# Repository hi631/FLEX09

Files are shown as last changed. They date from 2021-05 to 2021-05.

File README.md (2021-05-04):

<p><b><font size="+1"><span class="VIiyi" jsaction="mouseup:BR6jm" jsname="jqKxS" lang="en" style="-webkit-tap-highlight-color: transparent; display: inline; color: rgb(0, 0, 0); font-family: Roboto, RobotoDraft, Helvetica, Arial, sans-serif; font-size: 24px; font-style: normal; font-variant-ligatures: normal; font-variant-caps: normal; font-weight: 400; letter-spacing: normal; orphans: 2; text-align: start; text-indent: 0px; text-transform: none; white-space: pre-wrap; widows: 2; word-spacing: 0px; -webkit-text-stroke-width: 0px; background-color: rgb(245, 245, 245); text-decoration-thickness: initial; text-decoration-style: initial; text-decoration-color: initial;"><span jsaction="agoMJf:PFBcW;usxOmf:aWLT7;jhKsnd:P7O7bd,F8DmGf;Q4AGo:Gm7gYd,qAKMYb;uFUCPb:pvnm0e,pfE8Hb,PFBcW;f56efd:dJXsye;EnoYf:KNzws,ZJsZZ,JgVSJc;zdMJQc:cCQNKb,ZJsZZ,zchEXc;Ytrrj:JJDvdc;tNR8yc:GeFvjb;oFN6Ye:hij5Wb" jscontroller="Zl5N8" jsmodel="SsMkhd" jsname="txFAF" class="JLqJ4b ChMk0b" data-language-for-alternatives="en" data-language-to-translate-into="ja" data-phrase-index="0" jsdata="uqLsIf;_;$7" style="-webkit-tap-highlight-color: transparent; cursor: pointer;"><span jsaction="click:qtZ4nf,GFf3ac,tMZCfe; contextmenu:Nqw7Te,QP7LD; mouseout:Nqw7Te; mouseover:qtZ4nf,c2aHje" jsname="W297wb" style="-webkit-tap-highlight-color: transparent;">Make 6809 with FPGA and run FLEX</span></span></span><span style="color: rgb(0, 0, 0); font-family: Roboto, RobotoDraft, Helvetica, Arial, sans-serif; font-size: 24px; font-style: normal; font-variant-ligatures: normal; font-variant-caps: normal; font-weight: 400; letter-spacing: normal; orphans: 2; text-align: start; text-indent: 0px; text-transform: none; white-space: pre-wrap; widows: 2; word-spacing: 0px; -webkit-text-stroke-width: 0px; background-color: rgb(245, 245, 245); text-decoration-thickness: initial; text-decoration-style: initial; text-decoration-color: initial; display: inline !important; float: none;"> </span></font></b></p>
<p><font size="+1">#Simulator (SIM6809)</font><br>
<a>original material</a>[<a href="https://github.com/gordonjcp/sim6809">SIM6809</a>]<br>
SIM6809 is compiled with MINGW32.<br>
Start MINGW32 and move to the source directory with &quot;cd / C / ...... / sim6809&quot;,<br>
Compile with one make, start with &quot;./sim6809&quot; and the prompt should appear.<br>
<br>
<font size="+1"># FLEX</font><br>
Portable by adding serial and SD drivers to DRIVER (file is CONSOLE).<br>
The OS is localized to  $ C000-  $ FFFF, and it may not be possible to
move. The user area is 48KB.<br>
Add necessary processing (input / output) and check the operation of the assembled HEX with the simulator.<br>
<br>
There is a sample of access to the SD card at [<a href="https://github.com/nealcrook/multicomp6809">MULTICOMP6809</a>].<br>
However, FLEX has 256 bytes / sector, while SD card has 512 bytes / sector.<br>
The sample was a method that did not use half of the 512 bytes, but it was divided R / W using a buffer.<br>
<br>
Batch job &quot;_flex_SIM.bat&quot; creates HEX for the simulator.<br>
* Drive is R / W for files on Windows.<br>
Batch job &quot;_flex_FPGA.bat&quot; creates HEX for FPGA.<br>
* The drive is R / W by dividing the SD card.<br>
<br>
Furthermore, since it does not work under windows already, use an extender called msdos.exe.<br>
[<a href="http://takeda-toshiya.my.coocan.jp/msdos/">MS-DOS Player for Win32-x64</a>] <br>
<br>
<font size="+1"># FPGA6809 hard</font><br>
It would be easier to understand the configuration by looking at [<a href="http://searle.x10host.com/Multicomp/index.html">Grant's MULTICOMP</a>].<br>
* Almost as it is. However, VHDL is converted to verilog.<br>
6809 is operating at 30MHz.<br>
The SD card gives the driver 20MHz, so it probably works at 10MHz.<br>
<br>
Green is EP2C5 mounted board, black and big is FPGA<br>
The board on it is a board with RAM and SD made by CNC<br>
The lower right is the serial board (commercially available FTD1232)<br>
The upper right is the VGA output and PS2 input board (not connected in this software)<br>
<br>
<font size="+1">#FPGA6809 software</font><br>
The software can be compiled with quartus II.<br>
EP2C5 is an old generation Cyclone II, so be careful as it can only be compiled before 13.0sp1.<br>
1. If you want to run BASIC, assemble basic.asm.<br>
2. If you want to run monitor, assemble monitor.asm.<br>
* Both generate basic.hex, so there is no need to change the verilog side.<br>
<br>
<font size="+1">#Monitor program</font><br>
Used for starting FLEX and debugging when FLEX does not start.<br>
Starting FLEX is<br>
1. After starting the monitor, press'B'+'Ret' to start. (Pre-setting required)<br>
2. It is also possible to start from BASIC, and'%' is displayed by'Ctrl' +'L', so copy and paste the FLEX HEX file on the screen.<br>
Automatically start after the message &quot;% %%% ...&quot; is displayed<br>
* It is assumed that basic.asm (modified version) under the moni09 directory is used. It will be started from \ $ C400.<br>
The monitor is localized in two places,  $ E000 and \  A000, and starts
as  $ A000 at the time of reset.<br>
After copying itself to the RAM of \  A000, invalidate the ROM and free
up the FLEX load area.<br>
<br>
<font size="+1">#Drive layout on SD card</font><br>
0000-059F drive 0<br>
05A0 --05CF boot loader<br>
0800-0D9F drive 1<br>
1000-159F drive 2<br>
1800-1D9F drive 3<br>
* Described as 512B / S<br>
* 4 units can be selected, but the 4th unit cannot be used. (I feel like it's 3 in FLEX)<br>
For Card Day, use the command as shown below to combine the disks and write to SD with win32diskimager.<br>
Copy /b FLEX9SYS.DSK + DUMY_4CKFF.bin + BLANK.DSK + DUMY_4CKFF.bin + BLANK.DSK + DUMY_4CKFF.bin SD4M.img<br>
* Obtain FLEX9SYS.DSK from [<a href="http://www.evenson-consulting.com/swtpc/">SWTPC</a>]. I don't think there were any particular restrictions on use.<br>
<br>
<br>
<font size="+1">#Boot loader settings</font><br>
1. The monitor starts by resetting.<br>
2. Issue the'L'command. Check the'%' display.Copy and paste <br>
3.flex9.hexe to the terminal and load it into memory. (Written to $ C000-
$ FFFF)<br>
4. Issue a write command with'W 5001 C000 3F'.<br>
* 5001 is equivalent to  $ 800 sector (512B / S conversion) on the card.<br>
5. Confirm the operation with the'B'command.<br>
<br>
<a href="https://qiita.com/hi631/items/5b386fb230afcc87c66d">Here is</a> a little more detailed explanation (but in Japanese) <br>
<br>
</p>

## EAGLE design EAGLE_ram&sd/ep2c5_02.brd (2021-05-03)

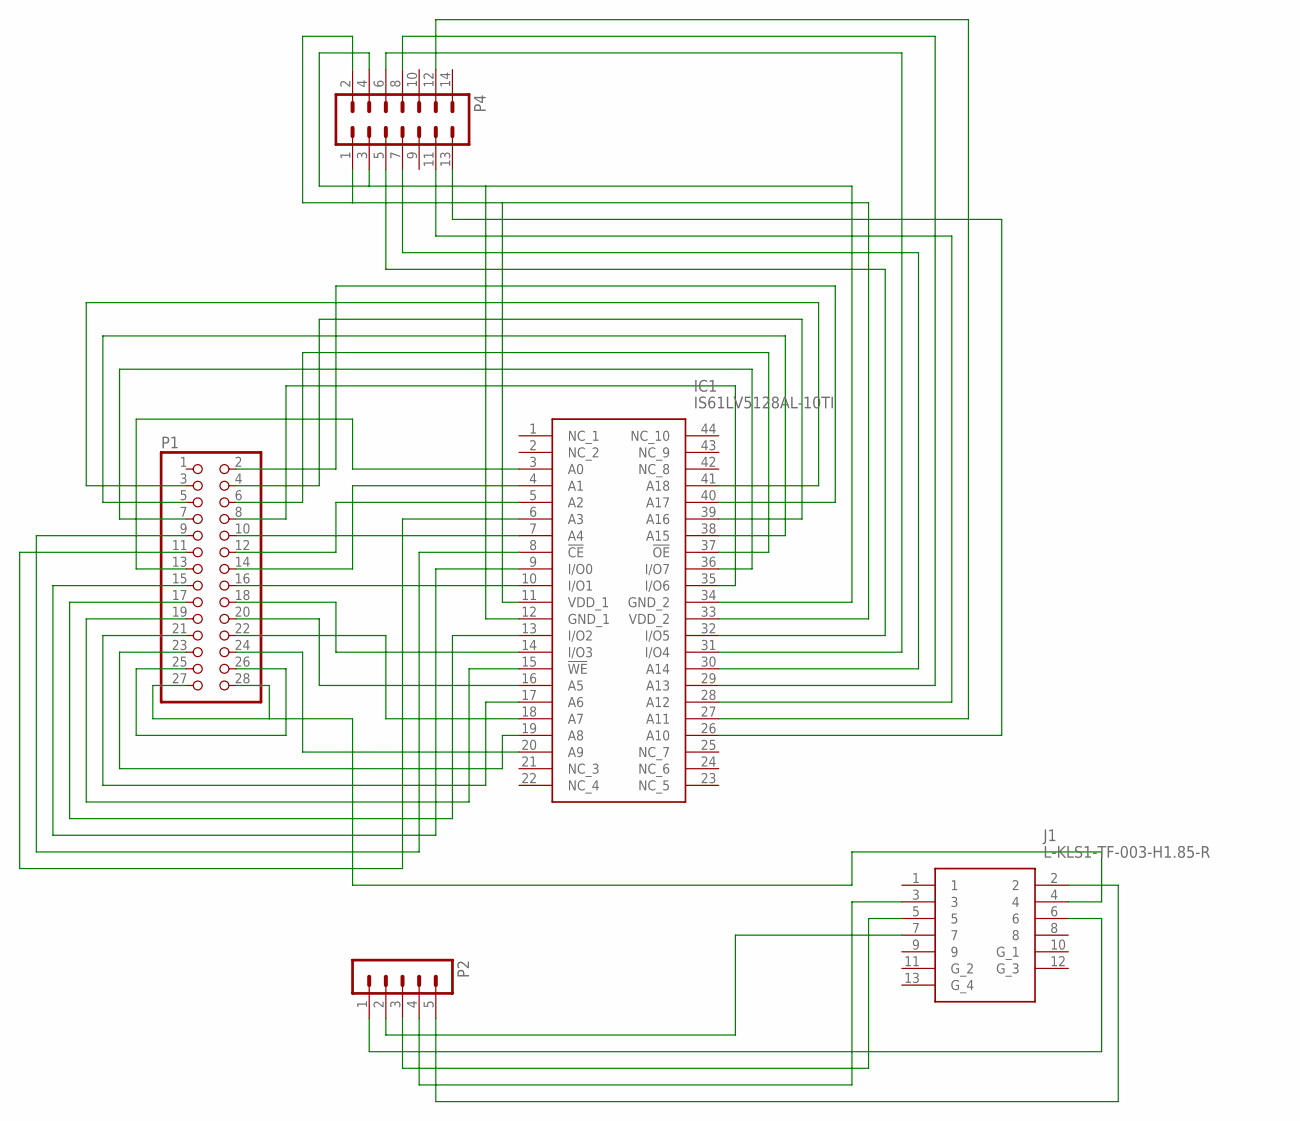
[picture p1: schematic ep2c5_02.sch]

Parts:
IC1: IS61LV5128AL-10TI; SOP80P1176X120-44N
J1: L-KLS1-TF-003-H1.85-R
P1: PINHD-2X14; 2X14
P2: MA05-1
P4: MA07-2

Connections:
unnamed: J1.4, P1.27, P1.28
unnamed: IC1.20 (A9), P1.24
unnamed: P1.25, P1.26
unnamed: IC1.19 (A8), P1.23
unnamed: IC1.18 (A7), P1.22
unnamed: IC1.17 (A6), P1.21
unnamed: IC1.16 (A5), P1.20
unnamed: IC1.15 (!WE), P1.19
unnamed: IC1.14 (I/O3), P1.18
unnamed: IC1.13 (I/O2), P1.17
unnamed: IC1.10 (I/O1), P1.16
unnamed: IC1.9 (I/O0), P1.15
unnamed: IC1.12 (GND_1), IC1.34 (GND_2), P4.3, P4.4
unnamed: IC1.8 (!CE), P1.9
unnamed: IC1.7 (A4), P1.10
unnamed: IC1.6 (A3), P1.11
unnamed: IC1.4 (A1), P1.14
unnamed: IC1.3 (A0), P1.13
unnamed: IC1.35 (I/O6), P1.8
unnamed: IC1.36 (I/O7), P1.7
unnamed: IC1.11 (VDD_1), IC1.33 (VDD_2), P4.1, P4.2
unnamed: IC1.37 (!OE), P1.6
unnamed: IC1.38 (A15), P1.5
unnamed: IC1.39 (A16), P1.4
unnamed: IC1.41 (A18), P1.3
unnamed: IC1.40 (A17), P1.2
unnamed: IC1.32 (I/O5), P4.5
unnamed: IC1.31 (I/O4), P4.6
unnamed: IC1.30 (A14), P4.7
unnamed: IC1.29 (A13), P4.8
unnamed: IC1.28 (A12), P4.11
unnamed: IC1.27 (A11), P4.12
unnamed: IC1.26 (A10), P4.13
unnamed: J1.7, P2.2
unnamed: J1.6, P2.1
unnamed: J1.5, P2.3
unnamed: J1.3, P2.4
unnamed: J1.2, P2.5
unnamed: IC1.5 (A2), P1.12

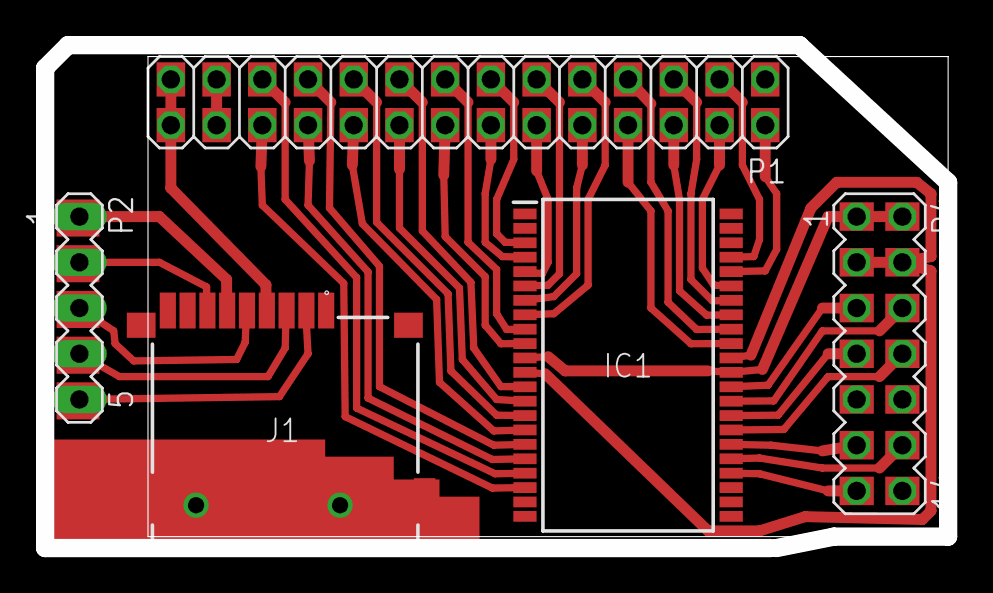
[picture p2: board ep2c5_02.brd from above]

Board: 2 copper layers, 44.5 x 26.7 mm, 5 parts (0 on the bottom side), 39 nets.

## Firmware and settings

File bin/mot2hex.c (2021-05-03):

/*
 * Motorola S1 format to Intel hex format
 * Usage
 * mot2hex <file_name>
 */

#include <stdio.h>
#include <string.h>


int gethex( FILE *fp_in )
{
    int hex;

    hex = fgetc( fp_in );
    if( (hex >= '0') && (hex <= '9' ))
	hex -= '0';
    else if( (hex >= 'A') && (hex <= 'F'))
	hex = hex - 'A' + 10;
    else
	hex = -1;
    return hex;
}

int get2hex( FILE *fp_in )
{
    int hexhi, hexlo, byte;

    hexhi = gethex( fp_in );
    if( hexhi != -1 )
    {
	hexlo = gethex( fp_in );
	if( hexlo != -1 )
	{
	    byte = hexhi * 16 + hexlo;
	    return byte;
	}
    }
    return -1;
}

int get4hex( FILE *fp_in )
{
    int bytehi, bytelo, addr;

    bytehi = get2hex( fp_in );
    if( bytehi != -1 )
    {
	bytelo = get2hex( fp_in );
	if( bytelo != -1 )
	{
	    addr = (bytehi * 256) + bytelo;
	    return addr;
	}
    }
    return -1;
}    


int main( int argc, char *argv[] )
{
	FILE *fp_in, *fp_out;
	char fname_in[32];
	char fname_out[32];
	int byte, addr, start, pstart,i;
        int motorola_check, intel_check;
	int motorola_count, intel_count;

	if( argc != 2 )
	{
	    printf( "\n usage: mot2hex <file_name> \n" );
	    return (0);
	}
 	sprintf( fname_in, "%s.s19", argv[1] );
	fp_in = fopen( fname_in, "r" );
	if( !fp_in )
	{
 	    sprintf( fname_in, "%s.s1", argv[1] );
            fp_in = fopen( fname_in, "r" );
	    if( !fp_in )
	    {
	        printf( "Can't open %s", fname_in );
	        return (0);
            }
	}
 	sprintf( fname_out, "%s.hex", argv[1] );
	fp_out = fopen( fname_out, "w" );
	if( !fp_out )
	{
	    printf( "Can't open %s", fname_out );
	    return (0);
	}
	byte = 0;
	addr = 0;
        start = -1; pstart = -1;

	while( byte != -1 )
	{
	    /*
	     * Motorola 8 bit record starts with "S1"
	     */
	    do {
		byte = fgetc( fp_in);
	    } while( (byte != 'S') && (byte != -1) );

	    byte = fgetc( fp_in );
	    if( byte == '1' )
	    {
		/*
		 * get byte count from Motorola record
		 */
		motorola_count = get2hex( fp_in );
	    motorola_check = motorola_count;
		/*
		 * Intel byte count is for data field only
		 * round up to even byte boundary
		 */
		intel_count = motorola_count - 3;
		intel_check = intel_count;
		/*
		 * Get two byte motorola address field
		 */
		addr = get4hex( fp_in );
                if(pstart==-1) pstart = addr;
	    motorola_check += (addr & 0xff); 
		motorola_check += (addr & 0xff00) >> 8;
		/*
		 * output intel start of record
		 * ":" <data count> <address> <record type>
		 */
		intel_check += (addr & 0xff);
		intel_check += (addr & 0xff00) >> 8;
	        fprintf( fp_out, ":%02X%04X00", intel_count, addr );
		/*
		 * Input Motorola data field
		 */
	    for( i=0; i<intel_count; i++ )
	        {
		    byte = get2hex( fp_in );
	            motorola_check += byte;
		    /*
		     * Output Intel data field
		     */
		    intel_check += byte;
		    fprintf( fp_out, "%02X", byte );
		    /*
		     * Get the start of record from the reset vector
		     */
	            if( addr == 0xfffe )
		        start = byte * 256;
	            if( addr == 0xffff )
		        start += byte;
		    addr ++;
		}
		/*
		 * Display Motorola cehcksum for current record
		 * should be 0xff
		 */	
	        byte = get2hex( fp_in) & 0xff;
	        motorola_check += byte;
		    motorola_check &= 0xff;
	        //printf( " Motorola checksum = %02X   ", motorola_check );
		/*
		 * Display Intel checksum
		 */
		intel_check &= 0xff;
		intel_check = 0x100 - intel_check;
		intel_check &= 0xff;
	        //printf( "Intel checksum = %02X \n", intel_check );
		/*
		 * Output Intel checksum
		 */
	        fprintf( fp_out, "%02X\n", intel_check);
	        if( addr > 0xffff )
		   byte = -1;
	     }
	}
	/*
	 * output Intel trasfer address
	 */
	//if( start != -1 )
	{
	    fprintf( fp_out, ":00%04X01", pstart );
	}
	/*
	 * Close input and output files and exit
	 */
	fclose( fp_in );
	fclose( fp_out );
}

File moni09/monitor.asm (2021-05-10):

ROMBASE   EQU  $9000          MONITOR $9000=RUN.RAM  $A000=RUN.ROM(->RAM)

UART      EQU  $FFD0
RECEV     EQU  UART+1
TRANS     EQU  UART+1
USTAT     EQU  UART
UCTRL     EQU  UART
SYSCTRL   EQU  $FFFF
RTS_LOW   EQU  $15

BS        EQU  8              BACKSPACE
CR        EQU  $D             ENTER KEY
ESC       EQU  $1B            ESCAPE CODE
SPACE     EQU  $20            SPACE (BLANK)

          ORG  $200          MONITOR WORK
MONCMD    RMB  1
MONAD     RMB  2
MONAD2    RMB  2
MONAD3    RMB  2
MONWK0    RMB  1
MONWK1    RMB  1
HLOADAD   RMB  2
HLOADDL   RMB  1
HLOADWK   RMB  1
HNINPWK   RMB  1

          ORG  ROMBASE
          JMP  BSTART           BASIC ENTRY
RSTART    LDS  #$1EE		RESET START
          LDX  #ROMBASE
          LDA  #$5A
          STA  -1,X
          LDB  #$A5
          STB  -2,X
          CMPA -1,X		IS RAM ?
          BNE  MONI
RSTARTLP  LDA  0,X		COPY ROM -> RAM
          STA  0,X
          LEAX 1,X
          CMPX #ROMBASE+$2000
          BNE  RSTARTLP
BSTART    
          PSHS X,Y,B,A
          LDA  #$81
          STA  SYSCTRL		DISALE BASIC.ROM
          BSR  MONI
          LDA  #$00
          STA  SYSCTRL		ENABLE BASIC.ROM
          PULS A,B,Y,X
          CLRA
          RTS

DLYT      CLRA
DLYA      DECA
          BNE  DLYA
          RTS
INITACIA  LDA  #3             RESET ACIA
          STA  UCTRL
          BSR  DLYT
          LDA  #RTS_LOW       DIV16 CLOCK -> 7372800 / 4 / 16 = 115200
          STA  UCTRL
          BSR  DLYT
          RTS

MONI      BSR  INITACIA
          LDX  #INITMSG
          JSR  STROUT
          
MONI2     LDA  #$3E		>
          JSR  PUTCHR
          JSR  CONSINWE
          STA  MONCMD
          CMPA #$0D
          BEQ  MONI
          JSR  HNINP		MONAD <- INPUT.HEX
          
MONI3     LDA  MONCMD
          CMPA #$44		D = DUMP(D AAAA)
          BNE  MONI4
          JSR  DUMP
          LBRA  MONIE
MONI4     CMPA #$4C		L = LOAD(LOAD HEX)
          BNE  MONI5
          JSR  HLOAD
          BRA  MONIE
MONI5     CMPA #$53		S = SYSTEM(S81 OR S00)
          BNE  MONI6
          LDA  MONAD+1
          STA  SYSCTRL		SET SYS_CTRL
          BRA  MONIE
MONI6     CMPA #$46		F = FILL(F AAAA BBBB DD)
          BNE  MONI7
          JSR  FILLDT
          BRA  MONIE
MONI7     CMPA #$47		G = GO.PRG(G AAAA)
          BNE  MONI8
          LDX  MONAD
          JSR  0,X
          BRA  MONIE
MONI8     CMPA #$52		R = READ(R SDAD MEMAD SDLEN)
          BNE  MONI9
          CLRA
          JSR  SDRWC		SDREAD(256B)
          BRA  MONIE
MONI9     CMPA #$57		W = WRITE(W SDAD MEMAD SDLEN)
          BNE  MONI10
          LDA  #1
          JSR  SDRWC
          BRA  MONIE
MONI10    CMPA #$55		U = UINT.SELECT(U N)
          BNE  MONI11
          LDA  MONAD+1
          LDX  #SDFCBTMP
          STA  3,X		DRIVE.NO
          JSR  SDSELDRV
          LDX  #SDDRV
          LDA  0,X
          JSR  H2OUT
          LDD  1,X
          JSR  H4OUT
          BRA  MONIE
MONI11    CMPA #$42		B = BOOT
          BNE  MONI99
          LDD  #$5001		SD.ADDR = 80T/1S
          STD  MONAD2
          LDD  #$C000		MEM.ADDR = $C000
          STD  MONAD3
          CLR  MONCMD		CMD(READ)
          LDB  #$3F		LOOP.COUNT
          JSR  SDRWCLP
          LDX  #$CD00
          JSR  0,X		JMP FLEX
          BRA  MONIE

MONI99    CMPA #$51		Q
          BNE  MONIE
          RTS
MONIE     JSR  CROUT
          LBRA  MONI2

SDRWC     STA  MONCMD
          LDD  MONAD
          STD  MONAD2          SD.AD
          JSR  HNINP
          PSHS A
          LDD  MONAD
          STD  MONAD3          MEM.AD
          PULS A
          CMPA #$8D
          BEQ  SDRWEX           R/W ONE
          JSR  HNINP
          LDD  MONAD
          LDB  MONAD+1		LOOP COUNT
*
SDRWCLP   PSHS B
          BSR  SDRWEX
          LDD  MONAD2
          ADDD #1
          STD  MONAD2
          LDD  MONAD3
          ADDD #256
          STD  MONAD3
          PULS B
          DECB
          BNE  SDRWCLP
          RTS
          
SDRWEX    LDD  MONAD2		TRACK.SECTER
          LDX  MONAD3		R/W.BUF.ADR
          TST  MONCMD           0=READ / 1=WRITE
          BNE  SDRWEX2
          JSR  SDREAD
          RTS
SDRWEX2   JSR  SDWRITE		SDWRITE(256B)
          RTS

FILLDT    LDD  MONAD
          STD  MONAD2		START
          JSR  HNINP
          LDD  MONAD
          STD  MONAD3		END
          JSR  HNINP
          LDA  MONAD+1		FILL.DT
          LDX  MONAD2
FILDT2    STA  0,X
          CMPX MONAD3
          BNE  FILDT3
          RTS
FILDT3    LEAX 1,X
          BRA  FILDT2


DUMP      TST  HNINPWK
          BEQ  DUMPEX
          LDX  MONAD
          STX  MONAD2
DUMPEX    LDB  #8
          STB  MONWK0
DUMPLP2   LDX  MONAD2
          LDD  MONAD2
          JSR  H4OUT
          JSR  SPOUT
          LDB  #16
DUMPLP3   LDA  0,X
          LEAX 1,X
          JSR  H2OUT
          JSR  SPOUT
          DECB
          BNE  DUMPLP3
          STX  MONAD2
          JSR CROUT
          DEC  MONWK0
          LDB  MONWK0
          BNE  DUMPLP2
          RTS

H1IN      JSR  CONSIN
          CMPA #$3A
          BGE  H1IN2
          SUBA #$30
          RTS
H1IN2     CMPA #$47
          BGE  H1IN3
          SUBA #$37
          RTS
H1IN3     SUBA #$57
          RTS
HDTIN     BSR  H1IN
          ASLA
          ASLA
          ASLA
          ASLA
          STA  HLOADWK
          BSR  H1IN
          ADDA HLOADWK
          RTS
HLOAD     LDX  #LOADMSG
          JSR  STROUT
HLOAD1    LDA  #$25           DISPLAY '%'
          JSR  PUTCHR
          JSR  CONSIN
          CMPA #$3A           ? :
          BNE  HLOAD
          BSR  HDTIN          A = DL
          STA  HLOADDL
          BSR  HDTIN
          STA  HLOADAD        ADDRESS
          BSR  HDTIN
          STA  HLOADAD+1
          BSR  HDTIN
          BEQ  HLOAD2         00 = DATA.LINE
          JSR  CROUT
          LDD  HLOADAD
          JSR  H4OUT
          LDA  #$0D
          RTS
HLOAD2    LDX  HLOADAD
          LDB  HLOADDL
HLOAD3    BSR  HDTIN
          STA  ,X+
          DECB
          BNE  HLOAD3
          BSR  HDTIN          SUM(DUMY.READ)
          jSR  CONSIN         CR (DUMY.READ)
          BRA  HLOAD1
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
